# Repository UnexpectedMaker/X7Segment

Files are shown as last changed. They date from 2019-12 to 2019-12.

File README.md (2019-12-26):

# X7Segment Display
X7 Segment displays are RGB LED based 7 Segment boards that you can chain together and control via any micro-controller just like you would control a strip of RGB LEDs. They just require VCC, GND and Data from a GPIO.

You can purchase these displays pre-built on [tindie](https://www.tindie.com/products/16900/)

I have released this project as open source, so if you would like you make your own for personal use, you can download the CAD files from this repo.

The hardware has been released as open source under the CERN license. Please review the license before using these files in your own projects to understand your obligations.

The software has been released as open source under the MIT license. Please review the license before using these files in your own projects to understand your obligations.

# X7Segment Display Library
An API that lets you display numbers and letters on X7Segment RGB LED displays that are available from [tindie](https://www.tindie.com/products/16900/)

You can find the Open Source hardware PCB design and Gerber files [here](https://github.com/UnexpectedMaker/X7Segment/CAD)

# Support Unexpected Maker

I love designing, making and releasing our projects as open source. I do it because I believe it’s important to share knowledge and give back to the community, like many have done before me. It helps us all learn and grow.

That said, a lot of time, effort and finances have gone into designing and releasing these files, so please consider supporting me by buy some of my TiinyPICO products:

https://tinypico.com/shop

Or by buying one of our products on tindie:

https://www.tindie.com/stores/seonr/

Or by becoming a Patron:

https://www.patreon.com/unexpectedmaker

# Unexpected Maker
http://youtube.com/c/unexpectedmaker

http://twitter.com/unexpectedmaker

https://www.facebook.com/unexpectedmaker/

https://www.instagram.com/unexpectedmaker/

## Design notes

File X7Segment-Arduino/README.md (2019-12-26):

# X7Segment Display Arduino Library
An API that lets you display numbers and letters on X7Segment RGB LED displays that are available from [tindie](https://www.tindie.com/products/16900/)

This software has been released as open source under the MIT license. Please review the license before using these files in your own projects to understand your obligations.

## Installing and Use
The downloaded code should be added to your arduino IDE libraries folder, and the library requires the [Adafruit NeoPixel library](https://github.com/adafruit/Adafruit_NeoPixel) for it to function.

To include the X7Segment library in your project:

    #include <X7Segment.h>

You can then initialise the display with the following line that includes the number of X7Segment digits and the GPIO to control them:

    X7Segment disp( 5, 4 );

You then start the display with the begin method, passing the brightness:

    disp.Begin(20);

The you simply pass the display the String you would like displayed and a color:

    disp.DisplayText( "1234", disp.Color( 255,0,0) );

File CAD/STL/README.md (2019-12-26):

# X7Segment Display Segment STL
This is the 3D printed segment used on the X7Segment RGB LED displays that are available from [tindie](https://www.tindie.com/products/16900/)

To print your own, use Transparent/Clear PLA, 100% in-fill, at 0.2mm layer height, and place them face down with the pegs pointing up.

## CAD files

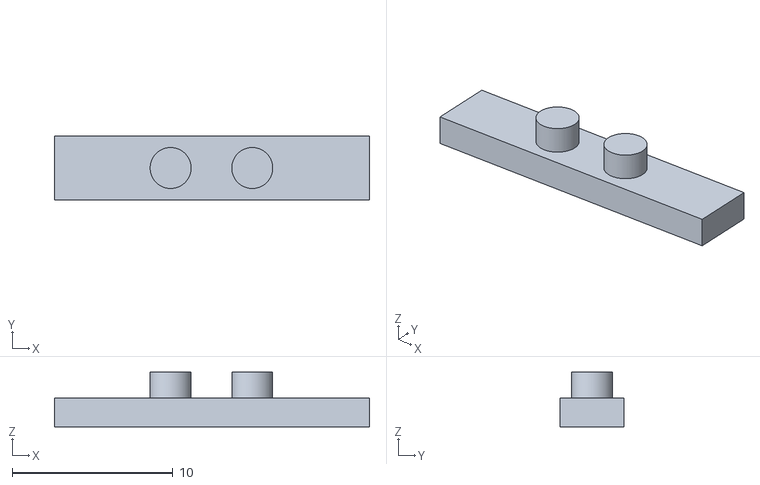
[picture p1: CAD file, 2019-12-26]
CAD/STL/Segment.stl
19.6 x 4.00 x 3.40

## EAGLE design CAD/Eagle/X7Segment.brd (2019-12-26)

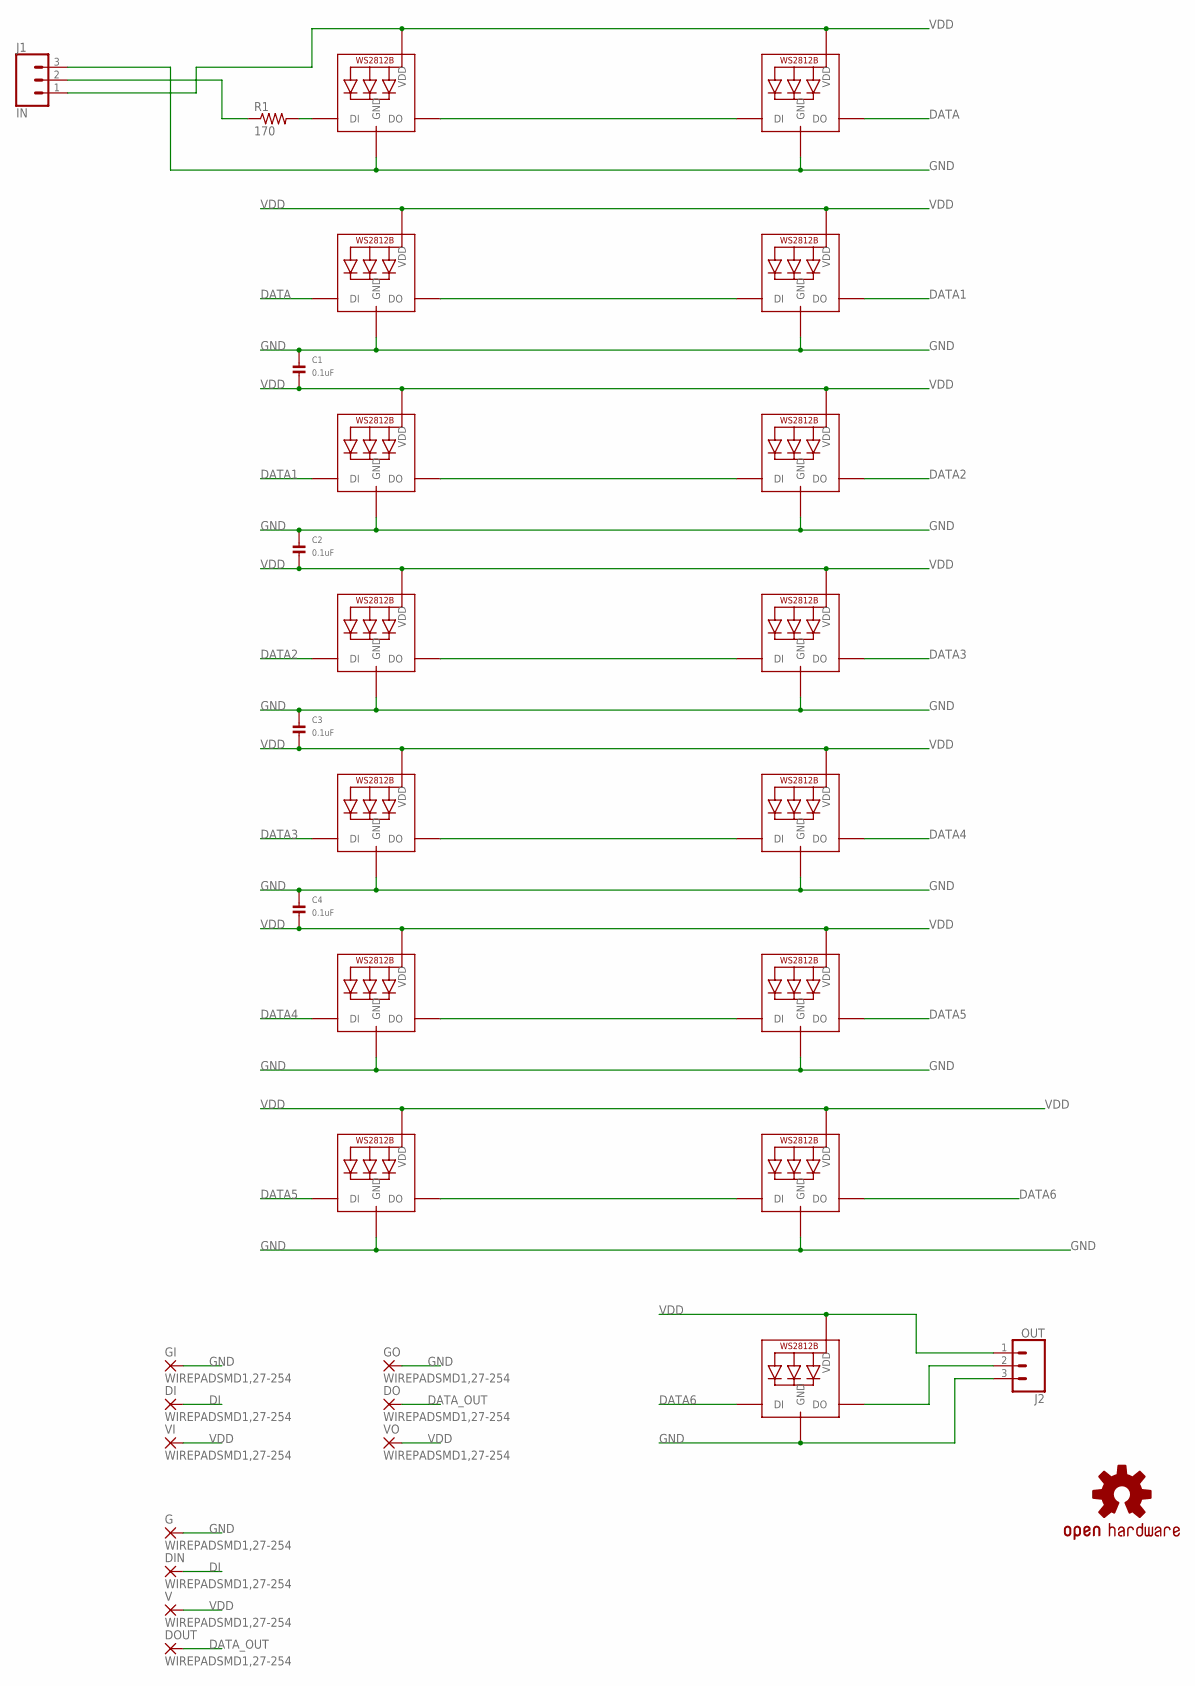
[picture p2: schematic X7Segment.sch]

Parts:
C1, C2, C3, C4: 0.1uF; _0603MP
DI: WIREPADSMD1,27-254; SMD1,27-2,54
DIN: WIREPADSMD1,27-254; SMD1,27-2,54
DO: WIREPADSMD1,27-254; SMD1,27-2,54
DOUT: WIREPADSMD1,27-254; SMD1,27-2,54
G: WIREPADSMD1,27-254; SMD1,27-2,54
GI: WIREPADSMD1,27-254; SMD1,27-2,54
GO: WIREPADSMD1,27-254; SMD1,27-2,54
J1: IN; 1X03_NO_SILK
J2: OUT; 1X03_NO_SILK
LED1, LED4, LED5, LED8, LED9, LED12, LED13, LED16, LED17, LED20, LED21, LED24, LED25, LED28: WS2812B4020_SIDEWAYS; 4020_SIDEWAYS
LED29: RGB 3535; LED3535
LOGO1: OSHW-LOGOS; OSHW-LOGO-S
R1: 170; R0805
V: WIREPADSMD1,27-254; SMD1,27-2,54
VI: WIREPADSMD1,27-254; SMD1,27-2,54
VO: WIREPADSMD1,27-254; SMD1,27-2,54

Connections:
DATA: LED4.2-DOUT (DO), LED5.4-DIN (DI)
DATA1: LED8.2-DOUT (DO), LED9.4-DIN (DI)
DATA2: LED12.2-DOUT (DO), LED13.4-DIN (DI)
DATA3: LED16.2-DOUT (DO), LED17.4-DIN (DI)
DATA4: LED20.2-DOUT (DO), LED21.4-DIN (DI)
DATA5: LED24.2-DOUT (DO), LED25.4-DIN (DI)
DATA6: LED28.2-DOUT (DO), LED29.1 (DI)
DATA_OUT: DO.1, DOUT.1, J2.2, LED29.3 (DO)
DI: DI.1, DIN.1, J1.2, R1.1
DI_R: LED1.4-DIN (DI), R1.2
GND: C1.1, C2.1, C3.1, C4.1, G.1, GI.1, GO.1, J1.3, J2.3, LED1.3-GND (GND), LED4.3-GND (GND), LED5.3-GND (GND), LED8.3-GND (GND), LED9.3-GND (GND), LED12.3-GND (GND), LED13.3-GND (GND), LED16.3-GND (GND), LED17.3-GND (GND), LED20.3-GND (GND), LED21.3-GND (GND), LED24.3-GND (GND), LED25.3-GND (GND), LED28.3-GND (GND), LED29.4 (GND)
unnamed: LED5.2-DOUT (DO), LED8.4-DIN (DI)
unnamed: LED9.2-DOUT (DO), LED12.4-DIN (DI)
unnamed: LED13.2-DOUT (DO), LED16.4-DIN (DI)
unnamed: LED21.2-DOUT (DO), LED24.4-DIN (DI)
unnamed: LED25.2-DOUT (DO), LED28.4-DIN (DI)
unnamed: LED1.2-DOUT (DO), LED4.4-DIN (DI)
unnamed: LED17.2-DOUT (DO), LED20.4-DIN (DI)
VDD: C1.2, C2.2, C3.2, C4.2, J1.1, J2.1, LED1.1-VDD (VDD), LED4.1-VDD (VDD), LED5.1-VDD (VDD), LED8.1-VDD (VDD), LED9.1-VDD (VDD), LED12.1-VDD (VDD), LED13.1-VDD (VDD), LED16.1-VDD (VDD), LED17.1-VDD (VDD), LED20.1-VDD (VDD), LED21.1-VDD (VDD), LED24.1-VDD (VDD), LED25.1-VDD (VDD), LED28.1-VDD (VDD), LED29.2 (VDD), V.1, VI.1, VO.1

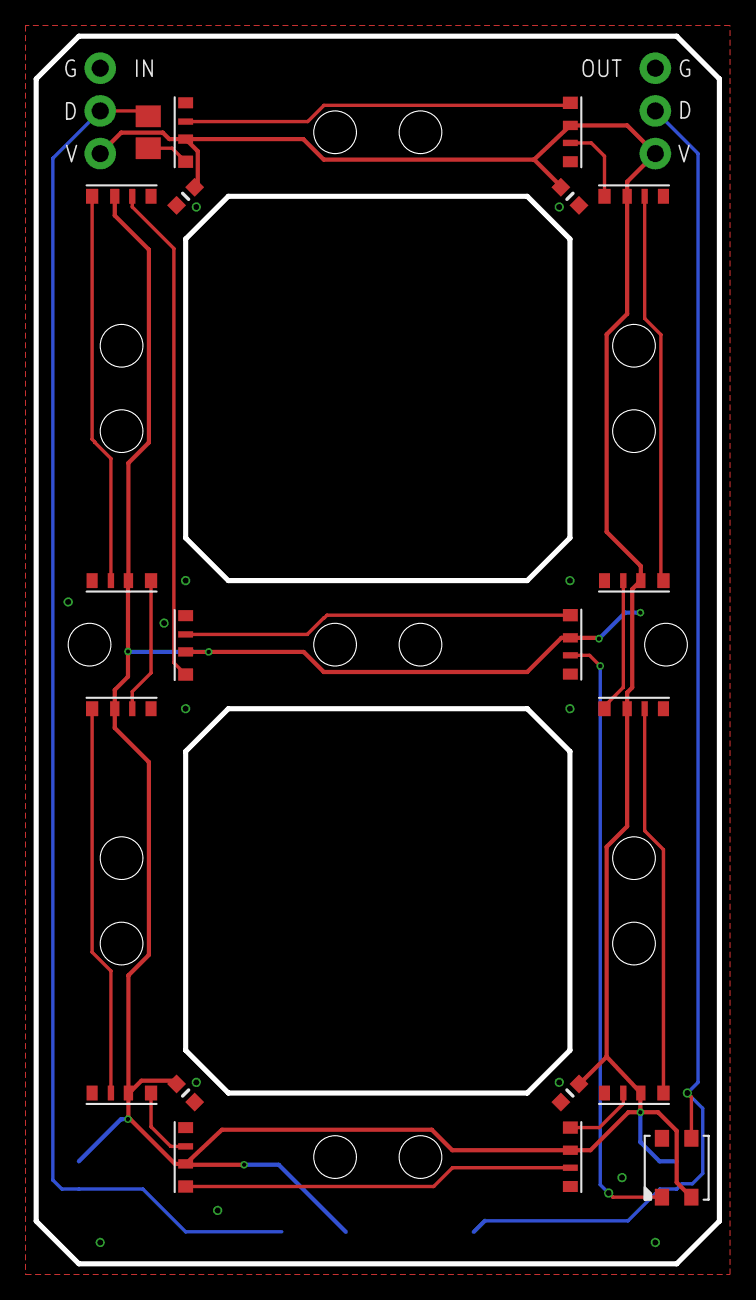
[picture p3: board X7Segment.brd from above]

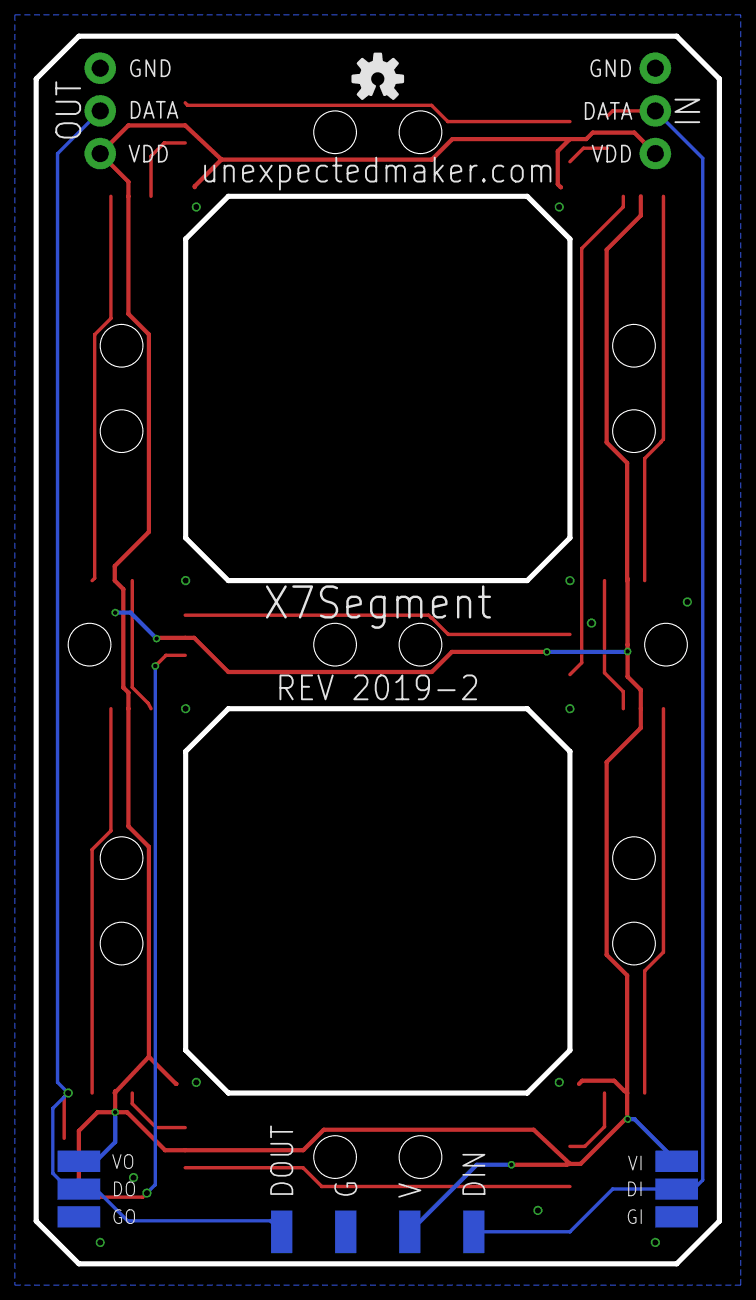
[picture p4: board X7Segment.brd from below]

Board: 2 copper layers, 40.6 x 73.0 mm, 33 parts (11 on the bottom side), 19 nets.

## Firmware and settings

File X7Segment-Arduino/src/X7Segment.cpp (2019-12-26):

// ---------------------------------------------------------------------------
// Created by Seon Rozenblum - seon@unexpectedmaker.com
// Copyright 2019 License: MIT https://github.com/UnexpectedMaker/X7Segment/LICENSE
//
// See "X7Segment.h" for purpose, syntax, version history, links, and more.
// ---------------------------------------------------------------------------

#include "X7Segment.h"

#if defined(ESP32)
    #include "freertos/FreeRTOS.h"
    #include "freertos/task.h"
    #include "freertos/event_groups.h"
    #include "esp32-hal.h"
#else
    // For non ESP32 boards, this library uses the Adafruit NeoPixel library - please check their licensing terms in their library.
    #include <Adafruit_NeoPixel.h>
#endif

#define DEBUG
#define NUM_PIXELS_PER_BOARD 15
#define NUM_PIXELS_PER_SEGMENT 2

// Array of pixels per segment, 7 segments with 4 pixels each
byte segmentsPixels[8][4] 	{ { 0, 1 }, 
                              { 2, 3 }, 
                              { 4, 5 }, 
                              { 6, 7 }, 
                              { 8, 9 }, 
                              {10, 11}, 
                              {12, 13},
							  { 14 }
						  	};

// Array of pixel positions in X,Y format for mapping colours in X,Y space
byte pixelsXY[15][2]		{ 	{ 1,0 }, { 2,0 },
								{ 3,1 }, { 3,2 },
	                          	{ 3,4 }, { 3,5 },
							   	{ 1,6 }, { 2,6 },
	                          	{ 0,5 }, { 0,4 },
							   	{ 0,2 }, { 0,1 },
	                          	{ 1,3 }, { 2,3 },
							   	{ 4,7 }
						  	};

// Available characters a 7 Segment display can show					  
const byte ARRAY_SIZE = 32;

byte available_codes[ ARRAY_SIZE ][ 2 ] {
							{ '0', 0b00111111  }, 
							{ '1', 0b00000110 },
							{ '2', 0b01011011 },
							{ '3', 0b01001111 },
							{ '4', 0b01100110 },
							{ '5', 0b01101101 },
							{ '6', 0b01111100 },
							{ '7', 0b00000111 },
							{ '8', 0b01111111 },
							{ '9', 0b01100111 },
							{ 'a', 0b01110111 },
							{ 'b', 0b01111100 },
							{ 'c', 0b00111001 },
							{ 'd', 0b01011110 },
							{ 'e', 0b01111001 },
							{ 'f', 0b01110001 },
							{ 'g', 0b01100111 },
							{ 'h', 0b01110110 },
							{ 'i', 0b00110000 },
							{ 'j', 0b00011110 },
							{ 'l', 0b00111000 },
							{ 'n', 0b01010100 },
							{ 'o', 0b01011100 },
							{ 'p', 0b01110011 },
							{ 'q', 0b01100111 },
							{ 'r', 0b01010000 },
							{ 's', 0b01101101 },
							{ 'u', 0b00111110 },
							{ 'x', 0b01110110 },
							{ 'y', 0b01101110 },
							{ '-', 0b01000000 },
							{ ' ', 0b00000000 }
						};

byte available_codes_upper[ ARRAY_SIZE ][ 2 ] {
							{ '0', 0b00111111 }, 
							{ '1', 0b00000110 },
							{ '2', 0b01011011 },
							{ '3', 0b01001111 },
							{ '4', 0b01100110 },
							{ '5', 0b01101101 },
							{ '6', 0b01111100 },
							{ '7', 0b00000111 },
							{ '8', 0b01111111 },
							{ '9', 0b01100111 },
							{ 'a', 0b01110111 },
							{ 'b', 0b01111111 },
							{ 'c', 0b00111001 },
							{ 'd', 0b00111111 },
							{ 'e', 0b01111001 },
							{ 'f', 0b01110001 },
							{ 'g', 0b01100111 },
							{ 'h', 0b01110110 },
							{ 'i', 0b00110000 },
							{ 'j', 0b00011110 },
							{ 'l', 0b00111000 },
							{ 'n', 0b00110111 },
							{ 'o', 0b00111111 },
							{ 'p', 0b01110011 },
							{ 'q', 0b01100111 },
							{ 'r', 0b00110001 },
							{ 's', 0b01101101 },
							{ 'u', 0b00111110 },
							{ 'x', 0b01110110 },
							{ 'y', 0b01101110 },
							{ '-', 0b01000000 },
							{ ' ', 0b00000000 }
						};					


													
X7Segment::X7Segment( uint8_t displayCount, uint8_t dPin )
{
	dispCount = displayCount;
	dispPin = dPin;

    ledCount = dispCount * NUM_PIXELS_PER_BOARD;
    leds = (uint32_t *) malloc( ledCount * sizeof(uint32_t));

    brightness = 90;

#if defined(ESP32)



#else

	pixels = Adafruit_NeoPixel ();
	pixels.updateType( NEO_GRB + NEO_KHZ800 );
  	pixels.updateLength( ledCount );
    pixels.setPin(dispPin);

#endif

    ClearBuffer();
	isReady = false;
}

X7Segment::~X7Segment()
{
	isReady = false;
}

bool X7Segment::IsReady()
{
	return isReady;
}

void X7Segment::Begin( uint8_t bright )
{
#if defined(ESP32)

    #ifdef DEBUG
        Serial.println("\nESP32 baby!!!");
    #endif

    led_data = (rmt_data_t *) malloc( ( 24 * ledCount ) * sizeof(rmt_data_t) );

     if ((rmt_send = rmtInit(dispPin, true, RMT_MEM_64)) == NULL)
    {
        #ifdef DEBUG
            Serial.println("init sender failed\n");
        #endif
    }

    float realTick = rmtSetTick(rmt_send, 100);
    #ifdef DEBUG
        Serial.printf("real tick set to: %fns\n", realTick);
    #endif

    brightness = bright;
#else
	pixels.begin(); // This initializes the NeoPixel library.
	pixels.show();
	pixels.setBrightness( bright );
#endif

	cachedString = "";
	cachedBytes = (byte *) malloc(dispCount * sizeof(byte));
	
	for ( int i = 0; i < dispCount; i++ )
		cachedBytes[i] = 0;

	#ifdef DEBUG
		Serial.print("Brightness: ");
		Serial.println(brightness);
		Serial.println("Ready!");
	#endif

	//Digits are initialised and ready
	isReady = true;
	isForcedUpper = false;
}

void X7Segment::SetBrightness( uint8_t bright )
{
	if ( isReady )
	{
        #if defined(ESP32)
            brightness = bright;
        #else
		    pixels.setBrightness( bright );
        #endif
	}
}

void X7Segment::ForceUppercase( bool force )
{
	isForcedUpper = force;
}

byte X7Segment::GetArraySize()
{
	return ARRAY_SIZE;
}

String X7Segment::GetCharacterAtArrayIndex( int index )
{
	return ( (String)(char)available_codes[ index ][0] );
}

void X7Segment::ClearBuffer()
{
	for ( int i = 0; i < ledCount; i++ )
        leds[i] = 0;
}

// Convert separate R,G,B into packed 32-bit RGB color.
// Packed format is always RGB, regardless of LED strand color order.
uint32_t X7Segment::Color(uint8_t r, uint8_t g, uint8_t b)
{
  return ((uint32_t)r << 16) | ((uint32_t)g <<  8) | b;
}

uint32_t X7Segment::gamma32(uint32_t x) {
  uint8_t *y = (uint8_t *)&x;
  // All four bytes of a 32-bit value are filtered even if RGB (not WRGB),
  // to avoid a bunch of shifting and masking that would be necessary for
  // properly handling different endianisms (and each byte is a fairly
  // trivial operation, so it might not even be wasting cycles vs a check
  // and branch for the RGB case). In theory this might cause trouble *if*
  // someone's storing information in the unused most significant byte
  // of an RGB value, but this seems exceedingly rare and if it's
  // encountered in reality they can mask values going in or coming out.
  for(uint8_t i=0; i<4; i++) y[i] = gamma8(y[i]);
  return x; // Packed 32-bit return
}
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

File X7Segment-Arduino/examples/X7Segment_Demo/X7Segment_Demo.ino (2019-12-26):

#include <X7Segment.h>

// Initalise the display with 5 X7Segment boards connected to GPIO 10
X7Segment disp( 5, 10 );

int loopIndex = 0;
byte rainbowIndex = 0;
unsigned long nextRainbow = 0;
int displayFeature = 0;
int nextSwitch = 10000;

void setup()
{
  Serial.begin(115200);
  delay(1000);

  // Start the display with a brightness value of 20
  disp.Begin(20);

  // Set the initial display feature to show as 0
  displayFeature = 0;
}

void loop()
{
  // Wait until the display is initialised before we try to show anything
  if ( !disp.IsReady() )
  {
    nextSwitch = millis();
    return;
  }

  // Switch what we are showing every 5 seconds
  if ( millis() > nextSwitch )
  {
    nextSwitch = millis() + 5000;
    displayFeature = ( displayFeature + 1 ) % 7;
    Serial.println(displayFeature);
  }

  // Display stuff on the Neo7Segment displays
  if ( nextRainbow < millis() )
  {
    switch( displayFeature )
    {
      case 0:
        for ( int i = 0; i < disp.GetArraySize(); i++ )
        {
          disp.DisplayTextColor( disp.GetCharacterAtArrayIndex(i), disp.Wheel( rainbowIndex & 255 ) );
          rainbowIndex+=10;
          delay(500);
        }
        break;
        
      case 1:
        disp.DisplayTextColorCycle( "12345", rainbowIndex );
        nextRainbow = millis() + 10;
        rainbowIndex++;
        break;

      case 2:
        disp.DisplayTextVerticalRainbow("     ", disp.Color(255,0,0), disp.Color(0,0,255) );
        delay(250);
        disp.DisplayTextVerticalRainbow("C    ", disp.Color(255,0,0), disp.Color(0,0,255) );
        delay(250);
        disp.DisplayTextVerticalRainbow("CL   ", disp.Color(255,0,0), disp.Color(0,0,255) );
        delay(250);
        disp.DisplayTextVerticalRainbow("CLE  ", disp.Color(255,0,0), disp.Color(0,0,255) );
        delay(250);
        disp.DisplayTextVerticalRainbow("CLEA ", disp.Color(255,0,0), disp.Color(0,0,255) );
        delay(250);
        disp.DisplayTextVerticalRainbow("CLEAR", disp.Color(255,0,0), disp.Color(0,0,255) );
        delay(1250);
        disp.DisplayTextVerticalRainbow(" LEAR", disp.Color(255,0,0), disp.Color(0,0,255) );
        delay(250);
        disp.DisplayTextVerticalRainbow("  EAR", disp.Color(255,0,0), disp.Color(0,0,255) );
        delay(250);
        disp.DisplayTextVerticalRainbow("   AR", disp.Color(255,0,0), disp.Color(0,0,255) );
        delay(250);
        disp.DisplayTextVerticalRainbow("    R", disp.Color(255,0,0), disp.Color(0,0,255) );
        delay(250);
        disp.DisplayTextVerticalRainbow("     ", disp.Color(255,0,0), disp.Color(0,0,255) );
        delay(500);
        nextSwitch = 0;
        break;

      case 3:
        disp.ForceUppercase( false );
        disp.DisplayTextVerticalRainbow("ABCDE", disp.Wheel( rainbowIndex & 255 ) , disp.Wheel( ( rainbowIndex + 50 ) & 255 )  );
        nextRainbow = millis() + 10;
        rainbowIndex--;
        break;
        
       case 4:
        disp.ForceUppercase( false );
        disp.DisplayTextHorizontalRainbow("67890", disp.Wheel( rainbowIndex & 255 ) , disp.Wheel( ( rainbowIndex + 150 ) & 255 )  );
        nextRainbow = millis() + 10;
        rainbowIndex--;
        break;
      
      case 5:
        disp.DisplayTime( 22, 16, (nextRainbow % 60), disp.Color(255, 200, 0), disp.Color(0, 0, 255) );
        nextRainbow = millis() + 500;
        break;

      case 6:
        disp.DisplayTextColorCycle( "0---0", rainbowIndex );
        nextRainbow = millis() + 10;
        rainbowIndex++;
        break;
       
    }
  }
}

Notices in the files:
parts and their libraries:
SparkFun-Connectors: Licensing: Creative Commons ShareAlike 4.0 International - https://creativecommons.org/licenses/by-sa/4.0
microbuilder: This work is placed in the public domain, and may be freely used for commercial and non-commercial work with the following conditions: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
